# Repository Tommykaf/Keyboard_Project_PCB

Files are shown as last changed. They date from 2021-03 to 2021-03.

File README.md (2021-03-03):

# keyboard_project

A Keyboard pcb modeled by @tommykark03, @thunde7, @wifi and @staveyal

## Parts

- MCU: ATMEGA32U4
- USB: TYPE-C-31-M-12
- DIODE: 1N4148W SOD-123

RESISTORS:
- 22 OHM - 0603WAF220JT5E
- 10k OHM - 0603WAF1002T5E
- 5.1K OHM - 0603WAF5101T5E

CAPACITORS:
- 1uF - CL10A105KB8NNNC
- 10uF - CL10A106KP8NNNC 
- 0.1uF (100pF) - CL10C101JB8NNNC

Quartz:
- Yangxing Tech X252016MLD4SC

Tactile reset:
- PANASONIC EVPBB4A9B000

Ferrite Bead:
- GZ1608D601TF

## layout

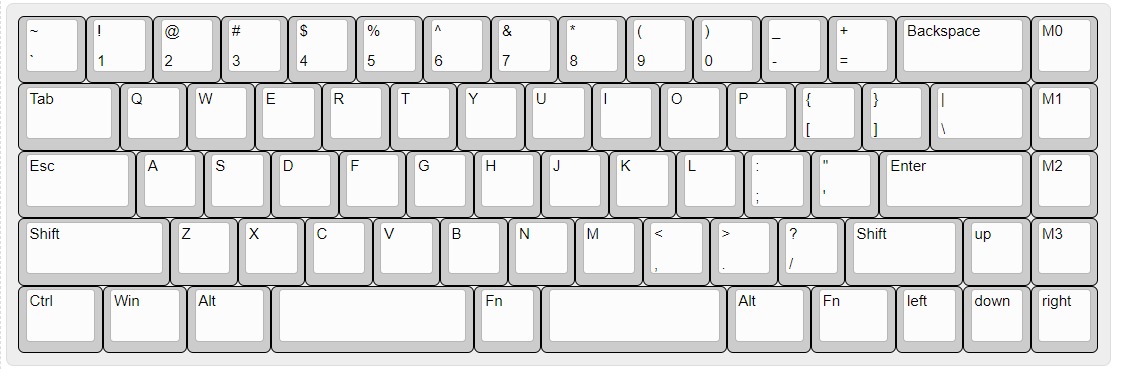
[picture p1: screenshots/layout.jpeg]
modified 65%


## MORE SCREENSHOTS
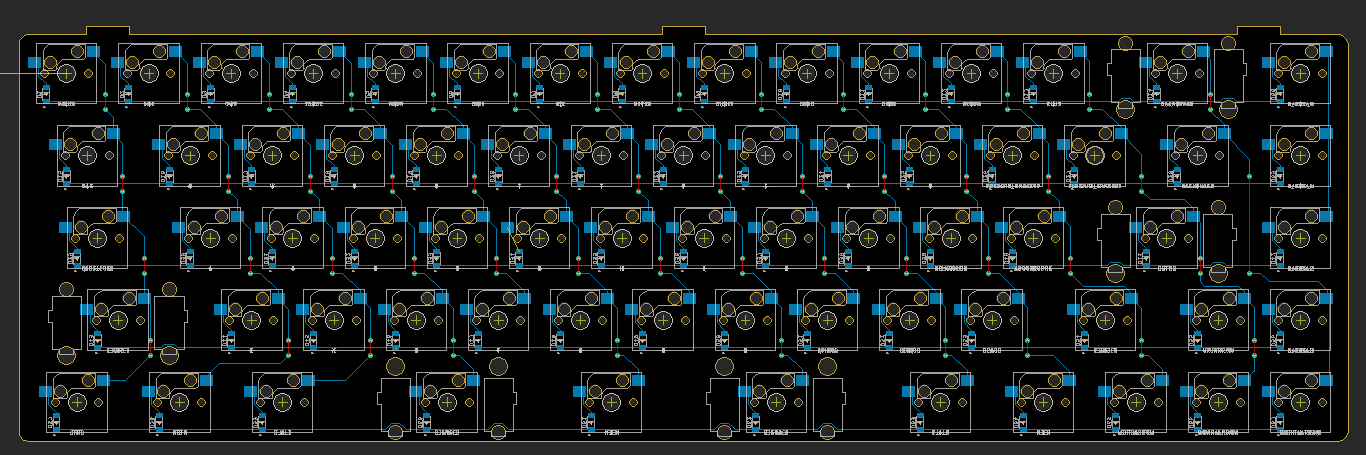
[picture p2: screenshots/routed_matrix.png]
routed matrix


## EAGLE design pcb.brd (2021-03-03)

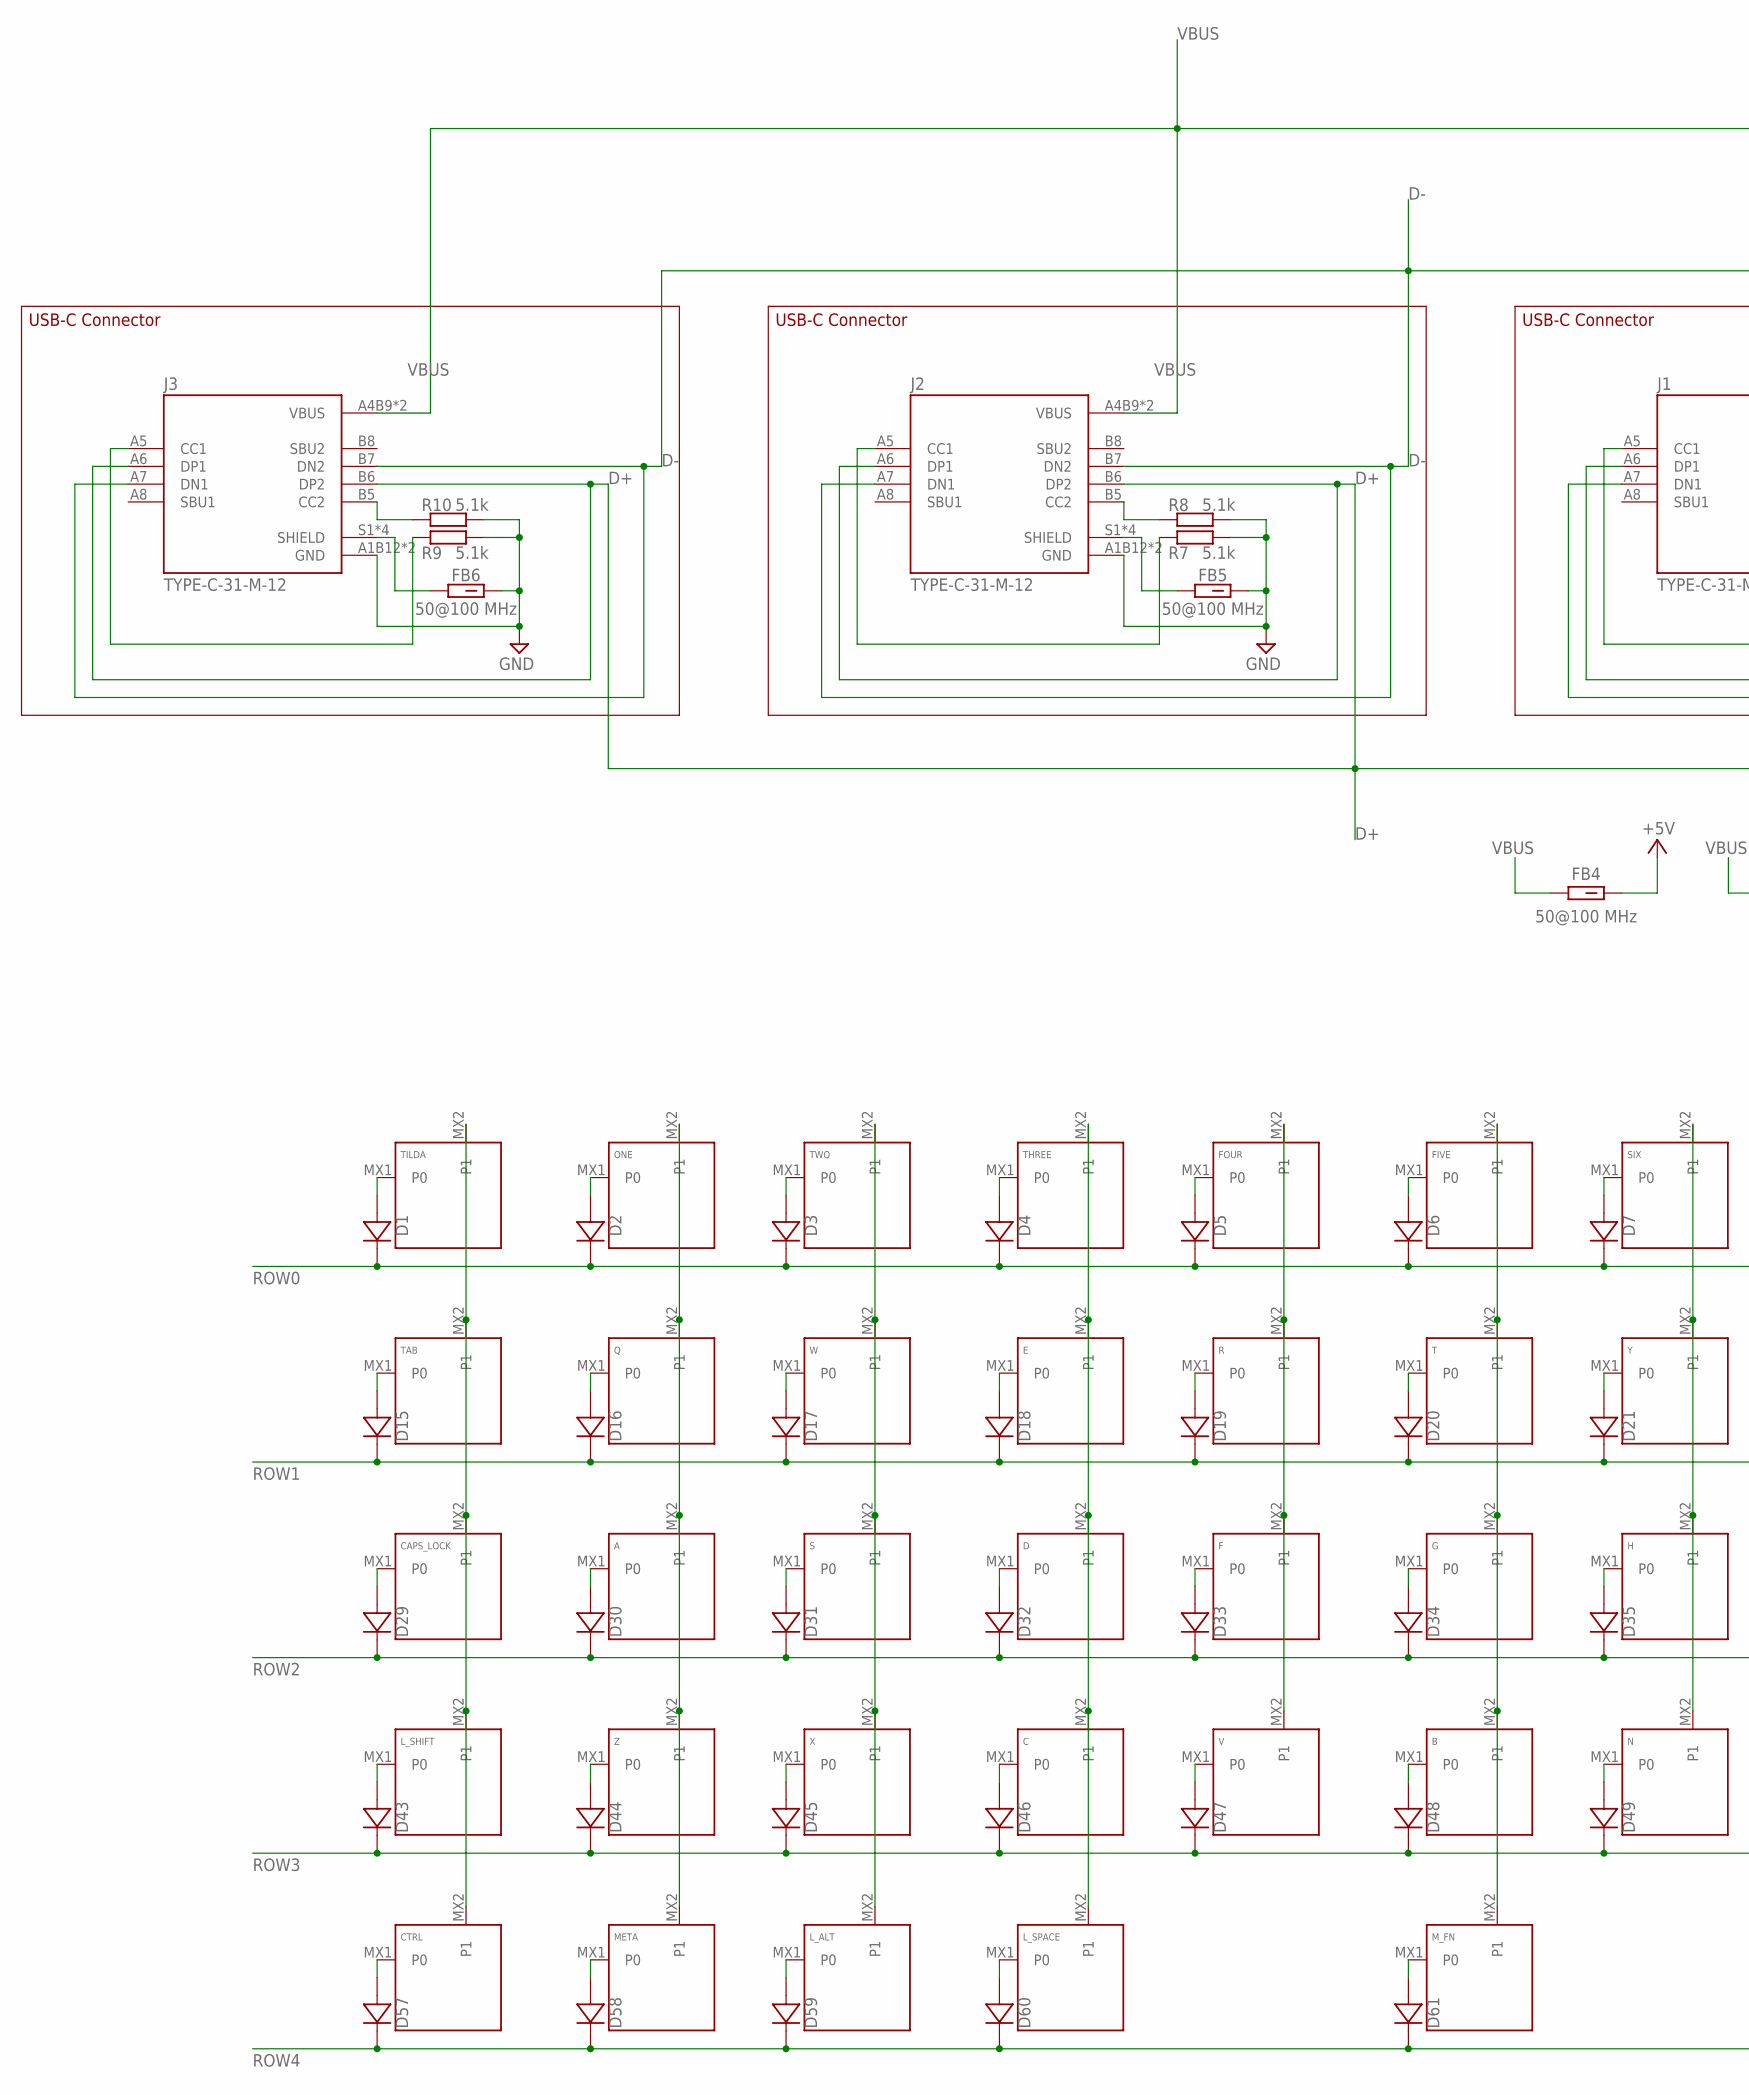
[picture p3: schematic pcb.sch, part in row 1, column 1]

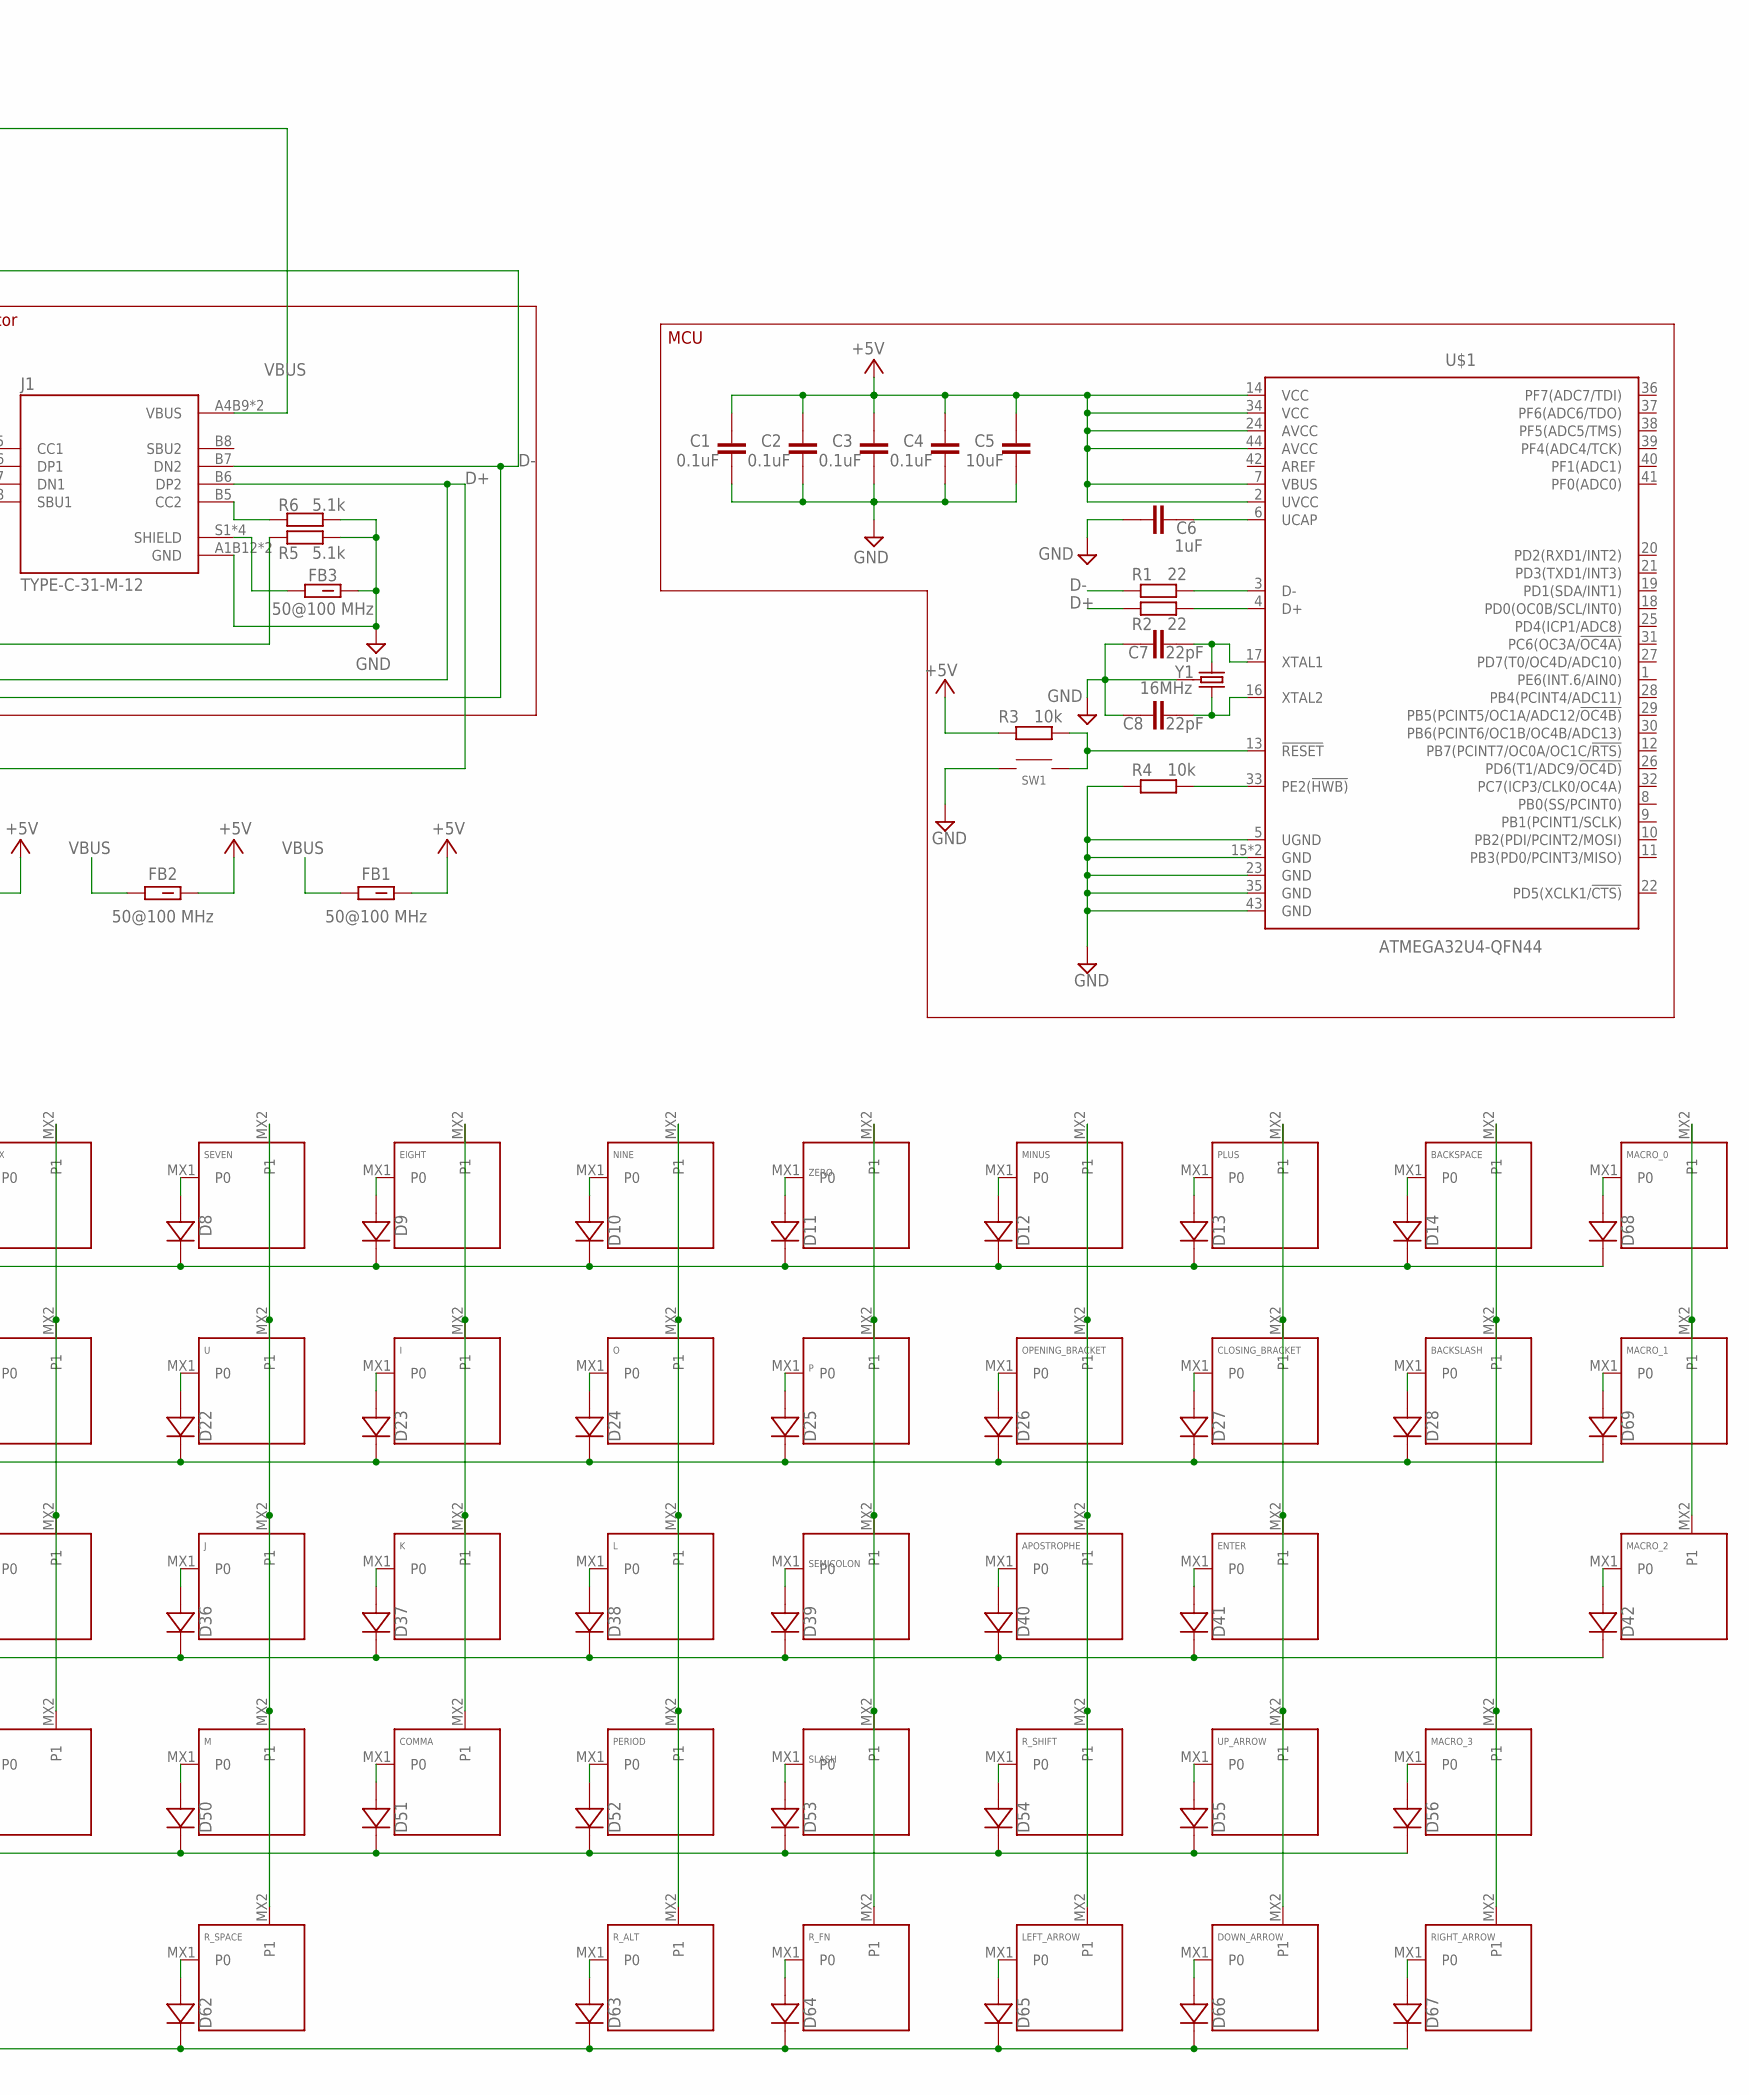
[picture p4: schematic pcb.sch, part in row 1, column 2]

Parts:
A: KEYSWITCH-PLAIN-MXHSPCB-1U; MXHSPCB-1U
APOSTROPHE: KEYSWITCH-PLAIN-MXHSPCB-1U; MXHSPCB-1U
B: KEYSWITCH-PLAIN-MXHSPCB-1U; MXHSPCB-1U
BACKSLASH: KEYSWITCH-PLAIN-MXHSPCB-1U; MXHSPCB-1U
BACKSPACE: KEYSWITCH-PLAIN-MXHSPCB-2U; MXHSPCB-2U
C: KEYSWITCH-PLAIN-MXHSPCB-1U; MXHSPCB-1U
C1, C2, C3, C4: 0.1uF; C0603
C5: 10uF; C0603
C6: 1uF; C0603
C7, C8: 22pF; C0603
CAPS_LOCK: KEYSWITCH-PLAIN-MXHSPCB-1U; MXHSPCB-1U
CLOSING_BRACKET: KEYSWITCH-PLAIN-MXHSPCB-1U; MXHSPCB-1U
COMMA: KEYSWITCH-PLAIN-MXHSPCB-1U; MXHSPCB-1U
CTRL: KEYSWITCH-PLAIN-MXHSPCB-1U; MXHSPCB-1U
D: KEYSWITCH-PLAIN-MXHSPCB-1U; MXHSPCB-1U
D1, D2, D3, D4, D5, D6, D7, D8, D9, D10, D11, D12, D13, D14, D15, D16, D17, D18, D19, D20, D21, D22, D23, D24, D25, D26, D27, D28, D29, D30, D31, D32, D33, D34, D35, D36, D37, D38, D39, D40, D41, D42, D43, D44, D45, D46, D47, D48, D49, D50, D51, D52, D53, D54, D55, D56, D57, D58, D59, D60, D61, D62, D63, D64, D65, D66, D67, D68, D69: DIODE-SOD-123; SOD-123
DOWN_ARROW: KEYSWITCH-PLAIN-MXHSPCB-1U; MXHSPCB-1U
E: KEYSWITCH-PLAIN-MXHSPCB-1U; MXHSPCB-1U
EIGHT: KEYSWITCH-PLAIN-MXHSPCB-1U; MXHSPCB-1U
ENTER: KEYSWITCH-PLAIN-MXHSPCB-2U; MXHSPCB-2U
F: KEYSWITCH-PLAIN-MXHSPCB-1U; MXHSPCB-1U
FB1, FB2, FB3, FB4, FB5, FB6: 50@100 MHz; BEADC1608X95N
FIVE: KEYSWITCH-PLAIN-MXHSPCB-1U; MXHSPCB-1U
FOUR: KEYSWITCH-PLAIN-MXHSPCB-1U; MXHSPCB-1U
G: KEYSWITCH-PLAIN-MXHSPCB-1U; MXHSPCB-1U
H: KEYSWITCH-PLAIN-MXHSPCB-1U; MXHSPCB-1U
I: KEYSWITCH-PLAIN-MXHSPCB-1U; MXHSPCB-1U
J: KEYSWITCH-PLAIN-MXHSPCB-1U; MXHSPCB-1U
J1, J2, J3: TYPE-C-31-M-12; HRO_TYPE-C-31-M-12
K: KEYSWITCH-PLAIN-MXHSPCB-1U; MXHSPCB-1U
L: KEYSWITCH-PLAIN-MXHSPCB-1U; MXHSPCB-1U
LEFT_ARROW: KEYSWITCH-PLAIN-MXHSPCB-1U; MXHSPCB-1U
L_ALT: KEYSWITCH-PLAIN-MXHSPCB-1U; MXHSPCB-1U
L_SHIFT: KEYSWITCH-PLAIN-MXHSPCB-2U; MXHSPCB-2U
L_SPACE: KEYSWITCH-PLAIN-MXHSPCB-2U-FLIPPED; MXHSPCB-2U-FLIPPED
M: KEYSWITCH-PLAIN-MXHSPCB-1U; MXHSPCB-1U
MACRO_0, MACRO_1, MACRO_2, MACRO_3: KEYSWITCH-PLAIN-MXHSPCB-1U; MXHSPCB-1U
META: KEYSWITCH-PLAIN-MXHSPCB-1U; MXHSPCB-1U
MINUS: KEYSWITCH-PLAIN-MXHSPCB-1U; MXHSPCB-1U
M_FN: KEYSWITCH-PLAIN-MXHSPCB-1U; MXHSPCB-1U
N: KEYSWITCH-PLAIN-MXHSPCB-1U; MXHSPCB-1U
NINE: KEYSWITCH-PLAIN-MXHSPCB-1U; MXHSPCB-1U
O: KEYSWITCH-PLAIN-MXHSPCB-1U; MXHSPCB-1U
ONE: KEYSWITCH-PLAIN-MXHSPCB-1U; MXHSPCB-1U
OPENING_BRACKET: KEYSWITCH-PLAIN-MXHSPCB-1U; MXHSPCB-1U
P: KEYSWITCH-PLAIN-MXHSPCB-1U; MXHSPCB-1U
PERIOD: KEYSWITCH-PLAIN-MXHSPCB-1U; MXHSPCB-1U
PLUS: KEYSWITCH-PLAIN-MXHSPCB-1U; MXHSPCB-1U
Q: KEYSWITCH-PLAIN-MXHSPCB-1U; MXHSPCB-1U
R: KEYSWITCH-PLAIN-MXHSPCB-1U; MXHSPCB-1U
R1, R2: 22; R0603
R3, R4: 10k; R0603
R5, R6, R7, R8, R9, R10: 5.1k; R0603
RIGHT_ARROW: KEYSWITCH-PLAIN-MXHSPCB-1U; MXHSPCB-1U
R_ALT: KEYSWITCH-PLAIN-MXHSPCB-1U; MXHSPCB-1U
R_FN: KEYSWITCH-PLAIN-MXHSPCB-1U; MXHSPCB-1U
R_SHIFT: KEYSWITCH-PLAIN-MXHSPCB-1U; MXHSPCB-1U
R_SPACE: KEYSWITCH-PLAIN-MXHSPCB-2U-FLIPPED; MXHSPCB-2U-FLIPPED
S: KEYSWITCH-PLAIN-MXHSPCB-1U; MXHSPCB-1U
SEMICOLON: KEYSWITCH-PLAIN-MXHSPCB-1U; MXHSPCB-1U
SEVEN: KEYSWITCH-PLAIN-MXHSPCB-1U; MXHSPCB-1U
SIX: KEYSWITCH-PLAIN-MXHSPCB-1U; MXHSPCB-1U
SLASH: KEYSWITCH-PLAIN-MXHSPCB-1U; MXHSPCB-1U
SW1: SWITCH-SMD-EVP-BB2A9B00
T: KEYSWITCH-PLAIN-MXHSPCB-1U; MXHSPCB-1U
TAB: KEYSWITCH-PLAIN-MXHSPCB-1U; MXHSPCB-1U
THREE: KEYSWITCH-PLAIN-MXHSPCB-1U; MXHSPCB-1U
TILDA: KEYSWITCH-PLAIN-MXHSPCB-1U; MXHSPCB-1U
TWO: KEYSWITCH-PLAIN-MXHSPCB-1U; MXHSPCB-1U
U: KEYSWITCH-PLAIN-MXHSPCB-1U; MXHSPCB-1U
U$1: ATMEGA32U4-QFN44; QFN-44
UP_ARROW: KEYSWITCH-PLAIN-MXHSPCB-1U; MXHSPCB-1U
V: KEYSWITCH-PLAIN-MXHSPCB-1U; MXHSPCB-1U
W: KEYSWITCH-PLAIN-MXHSPCB-1U; MXHSPCB-1U
X: KEYSWITCH-PLAIN-MXHSPCB-1U; MXHSPCB-1U
Y: KEYSWITCH-PLAIN-MXHSPCB-1U; MXHSPCB-1U
Y1: 16MHz; CRYSTAL-SMD-2X2.5MM
Z: KEYSWITCH-PLAIN-MXHSPCB-1U; MXHSPCB-1U
ZERO: KEYSWITCH-PLAIN-MXHSPCB-1U; MXHSPCB-1U

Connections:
+5V: FB1.2, FB2.2, FB4.2
D+: J1.A6 (DP1), J1.B6 (DP2), J2.A6 (DP1), J2.B6 (DP2), J3.A6 (DP1), J3.B6 (DP2), R2.1
D-: J1.A7 (DN1), J1.B7 (DN2), J2.A7 (DN1), J2.B7 (DN2), J3.A7 (DN1), J3.B7 (DN2), R1.1
GND: C1.1, C2.1, C3.1, C4.1, C5.1, C6.1, C7.1, C8.1, FB3.2, FB5.2, FB6.2, J1.A1B12 (GND), J1.B1A12 (GND), J2.A1B12 (GND), J2.B1A12 (GND), J3.A1B12 (GND), J3.B1A12 (GND), R4.1, R5.2, R6.2, R7.2, R8.2, R9.2, R10.2, SW1.A@1 (1), SW1.A@2 (1), U$1.5 (UGND), U$1.15 (GND), U$1.23 (GND), U$1.35 (GND), U$1.43 (GND), U$1.TAB (GND), Y1.P2 (GND), Y1.P4 (GND)
unnamed: D1.A, TILDA.MX1 (P0)
unnamed: D2.A, ONE.MX1 (P0)
unnamed: D3.A, TWO.MX1 (P0)
unnamed: D4.A, THREE.MX1 (P0)
unnamed: D5.A, FOUR.MX1 (P0)
unnamed: D6.A, FIVE.MX1 (P0)
unnamed: D7.A, SIX.MX1 (P0)
unnamed: D8.A, SEVEN.MX1 (P0)
unnamed: D9.A, EIGHT.MX1 (P0)
unnamed: D10.A, NINE.MX1 (P0)
unnamed: D11.A, ZERO.MX1 (P0)
unnamed: D12.A, MINUS.MX1 (P0)
unnamed: D13.A, PLUS.MX1 (P0)
unnamed: BACKSPACE.MX1 (P0), D14.A
unnamed: D15.A, TAB.MX1 (P0)
unnamed: D16.A, Q.MX1 (P0)
unnamed: D17.A, W.MX1 (P0)
unnamed: D18.A, E.MX1 (P0)
unnamed: D19.A, R.MX1 (P0)
unnamed: D20.A, T.MX1 (P0)
unnamed: D21.A, Y.MX1 (P0)
unnamed: D22.A, U.MX1 (P0)
unnamed: D23.A, I.MX1 (P0)
unnamed: D24.A, O.MX1 (P0)
unnamed: D25.A, P.MX1 (P0)
unnamed: D26.A, OPENING_BRACKET.MX1 (P0)
unnamed: CLOSING_BRACKET.MX1 (P0), D27.A
unnamed: BACKSLASH.MX1 (P0), D28.A
unnamed: CAPS_LOCK.MX1 (P0), D29.A
unnamed: A.MX1 (P0), D30.A
unnamed: D31.A, S.MX1 (P0)
unnamed: D.MX1 (P0), D32.A
unnamed: D33.A, F.MX1 (P0)
unnamed: D34.A, G.MX1 (P0)
unnamed: D35.A, H.MX1 (P0)
unnamed: D36.A, J.MX1 (P0)
unnamed: D37.A, K.MX1 (P0)
unnamed: D38.A, L.MX1 (P0)
unnamed: D39.A, SEMICOLON.MX1 (P0)
unnamed: APOSTROPHE.MX1 (P0), D40.A
unnamed: D41.A, ENTER.MX1 (P0)
unnamed: D42.A, MACRO_2.MX1 (P0)
unnamed: D43.A, L_SHIFT.MX1 (P0)
unnamed: D44.A, Z.MX1 (P0)
unnamed: D45.A, X.MX1 (P0)
unnamed: C.MX1 (P0), D46.A
unnamed: D47.A, V.MX1 (P0)
unnamed: B.MX1 (P0), D48.A
unnamed: D49.A, N.MX1 (P0)
unnamed: D50.A, M.MX1 (P0)
unnamed: COMMA.MX1 (P0), D51.A
unnamed: D52.A, PERIOD.MX1 (P0)
unnamed: D53.A, SLASH.MX1 (P0)
unnamed: D54.A, R_SHIFT.MX1 (P0)
unnamed: D55.A, UP_ARROW.MX1 (P0)
unnamed: D56.A, MACRO_3.MX1 (P0)
unnamed: CTRL.MX1 (P0), D57.A
unnamed: D58.A, META.MX1 (P0)
unnamed: D59.A, L_ALT.MX1 (P0)
unnamed: D60.A, L_SPACE.MX1 (P0)
unnamed: D62.A, R_SPACE.MX1 (P0)
unnamed: D63.A, R_ALT.MX1 (P0)
unnamed: D65.A, LEFT_ARROW.MX1 (P0)
unnamed: D67.A, RIGHT_ARROW.MX1 (P0)
unnamed: D69.A, MACRO_1.MX1 (P0)
unnamed: D68.A, MACRO_0.MX1 (P0)
unnamed: D61.A, M_FN.MX1 (P0)
unnamed: D66.A, DOWN_ARROW.MX1 (P0)
unnamed: D64.A, R_FN.MX1 (P0)
unnamed: CAPS_LOCK.MX2 (P1), CTRL.MX2 (P1), L_SHIFT.MX2 (P1), TAB.MX2 (P1), TILDA.MX2 (P1)
unnamed: A.MX2 (P1), META.MX2 (P1), ONE.MX2 (P1), Q.MX2 (P1), Z.MX2 (P1)
unnamed: L_ALT.MX2 (P1), S.MX2 (P1), TWO.MX2 (P1), W.MX2 (P1), X.MX2 (P1)
unnamed: C.MX2 (P1), D.MX2 (P1), E.MX2 (P1), L_SPACE.MX2 (P1), THREE.MX2 (P1)
unnamed: F.MX2 (P1), FOUR.MX2 (P1), R.MX2 (P1), V.MX2 (P1)
unnamed: B.MX2 (P1), FIVE.MX2 (P1), G.MX2 (P1), M_FN.MX2 (P1), T.MX2 (P1)
unnamed: H.MX2 (P1), N.MX2 (P1), SIX.MX2 (P1), Y.MX2 (P1)
unnamed: J.MX2 (P1), M.MX2 (P1), R_SPACE.MX2 (P1), SEVEN.MX2 (P1), U.MX2 (P1)
unnamed: COMMA.MX2 (P1), EIGHT.MX2 (P1), I.MX2 (P1), K.MX2 (P1)
unnamed: L.MX2 (P1), NINE.MX2 (P1), O.MX2 (P1), PERIOD.MX2 (P1), R_ALT.MX2 (P1)
unnamed: APOSTROPHE.MX2 (P1), LEFT_ARROW.MX2 (P1), MINUS.MX2 (P1), OPENING_BRACKET.MX2 (P1), R_SHIFT.MX2 (P1)
unnamed: P.MX2 (P1), R_FN.MX2 (P1), SEMICOLON.MX2 (P1), SLASH.MX2 (P1), ZERO.MX2 (P1)
unnamed: CLOSING_BRACKET.MX2 (P1), DOWN_ARROW.MX2 (P1), ENTER.MX2 (P1), PLUS.MX2 (P1), UP_ARROW.MX2 (P1)
unnamed: BACKSLASH.MX2 (P1), BACKSPACE.MX2 (P1), MACRO_3.MX2 (P1), RIGHT_ARROW.MX2 (P1)
unnamed: MACRO_0.MX2 (P1), MACRO_1.MX2 (P1), MACRO_2.MX2 (P1)
unnamed: R4.2, U$1.33 (PE2(!HWB))
unnamed: R3.2, SW1.B@3 (2), SW1.B@4 (2), U$1.13 (!RESET)
unnamed: C7.2, U$1.17 (XTAL1), Y1.P1 (1)
unnamed: C8.2, U$1.16 (XTAL2), Y1.P3 (2)
unnamed: R2.2, U$1.4 (D+)
unnamed: R1.2, U$1.3 (D-)
unnamed: C6.2, U$1.6 (UCAP)
unnamed: J2.A5 (CC1), R7.1
unnamed: J1.A5 (CC1), R5.1
unnamed: J1.B5 (CC2), R6.1
unnamed: J2.B5 (CC2), R8.1
unnamed: FB5.1, J2.S1 (SHIELD), J2.S2 (SHIELD), J2.S3 (SHIELD), J2.S4 (SHIELD)
unnamed: J3.A5 (CC1), R9.1
unnamed: FB3.1, J1.S1 (SHIELD), J1.S2 (SHIELD), J1.S3 (SHIELD), J1.S4 (SHIELD)
unnamed: J3.B5 (CC2), R10.1
unnamed: FB6.1, J3.S1 (SHIELD), J3.S2 (SHIELD), J3.S3 (SHIELD), J3.S4 (SHIELD)
ROW0: D1.C, D2.C, D3.C, D4.C, D5.C, D6.C, D7.C, D8.C, D9.C, D10.C, D11.C, D12.C, D13.C, D14.C, D68.C
ROW1: D15.C, D16.C, D17.C, D18.C, D19.C, D20.C, D21.C, D22.C, D23.C, D24.C, D25.C, D26.C, D27.C, D28.C, D69.C
ROW2: D29.C, D30.C, D31.C, D32.C, D33.C, D34.C, D35.C, D36.C, D37.C, D38.C, D39.C, D40.C, D41.C, D42.C
ROW3: D43.C, D44.C, D45.C, D46.C, D47.C, D48.C, D49.C, D50.C, D51.C, D52.C, D53.C, D54.C, D55.C, D56.C
ROW4: D57.C, D58.C, D59.C, D60.C, D61.C, D62.C, D63.C, D64.C, D65.C, D66.C, D67.C
VBUS: FB1.1, FB2.1, FB4.1, J1.A4B9 (VBUS), J1.B4A9 (VBUS), J2.A4B9 (VBUS), J2.B4A9 (VBUS), J3.A4B9 (VBUS), J3.B4A9 (VBUS)
VCC: C1.2, C2.2, C3.2, C4.2, C5.2, R3.1, U$1.2 (UVCC), U$1.7 (VBUS), U$1.14 (VCC), U$1.24 (AVCC), U$1.34 (VCC), U$1.44 (AVCC)

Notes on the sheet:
USB-C Connector
MCU

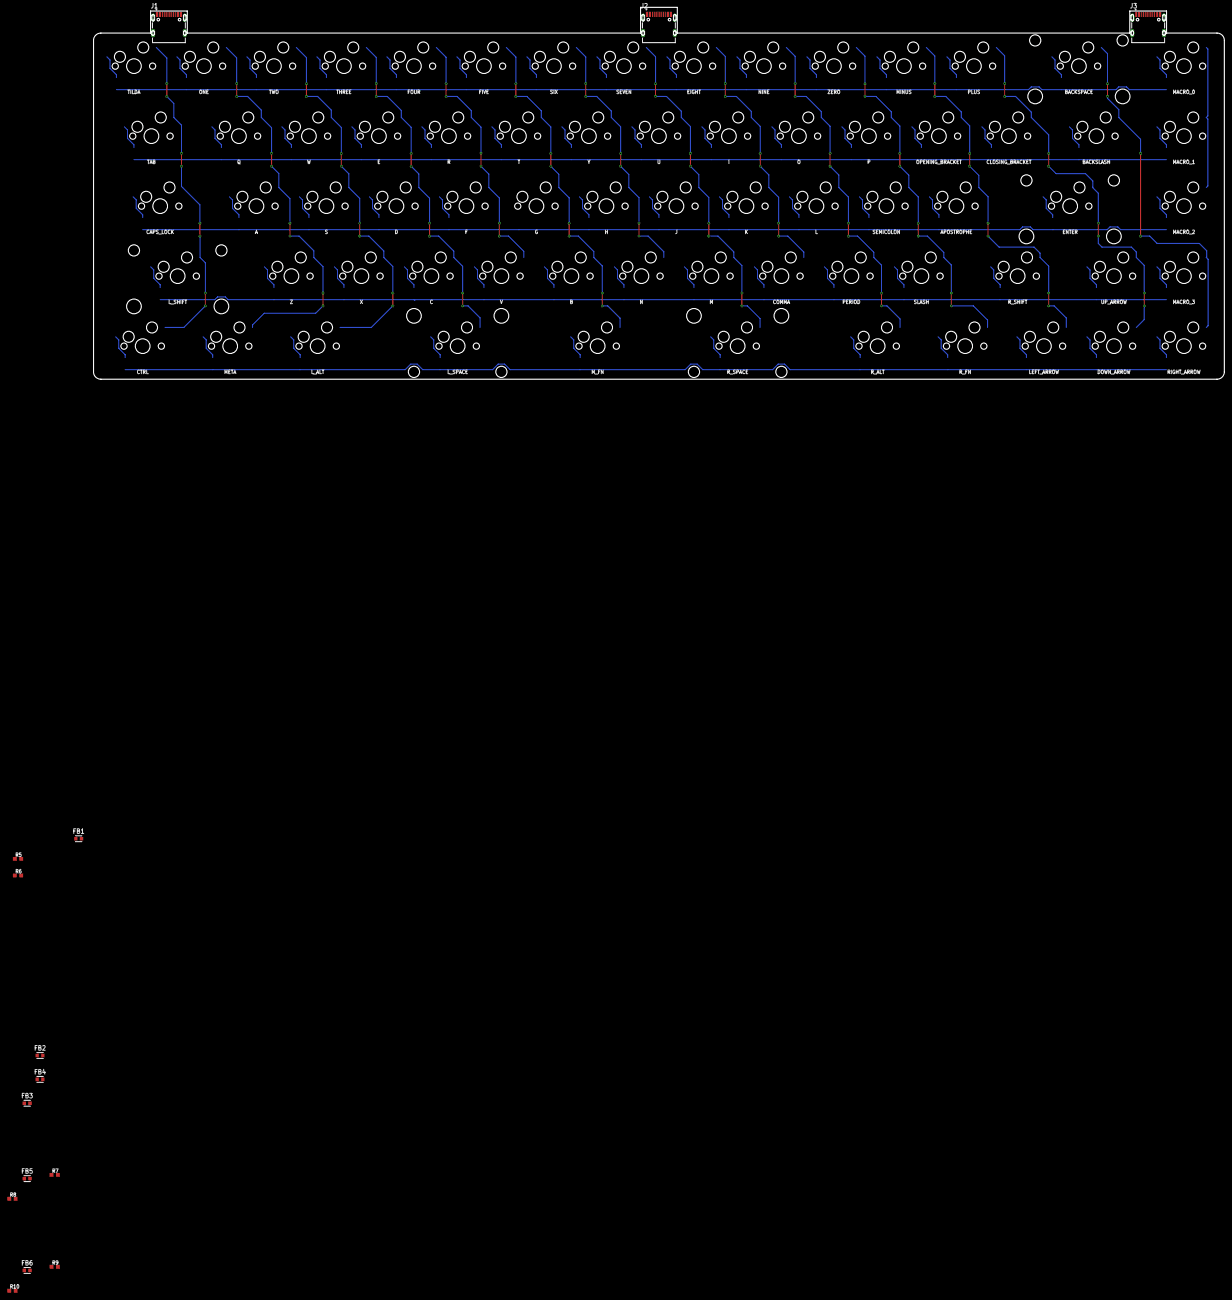
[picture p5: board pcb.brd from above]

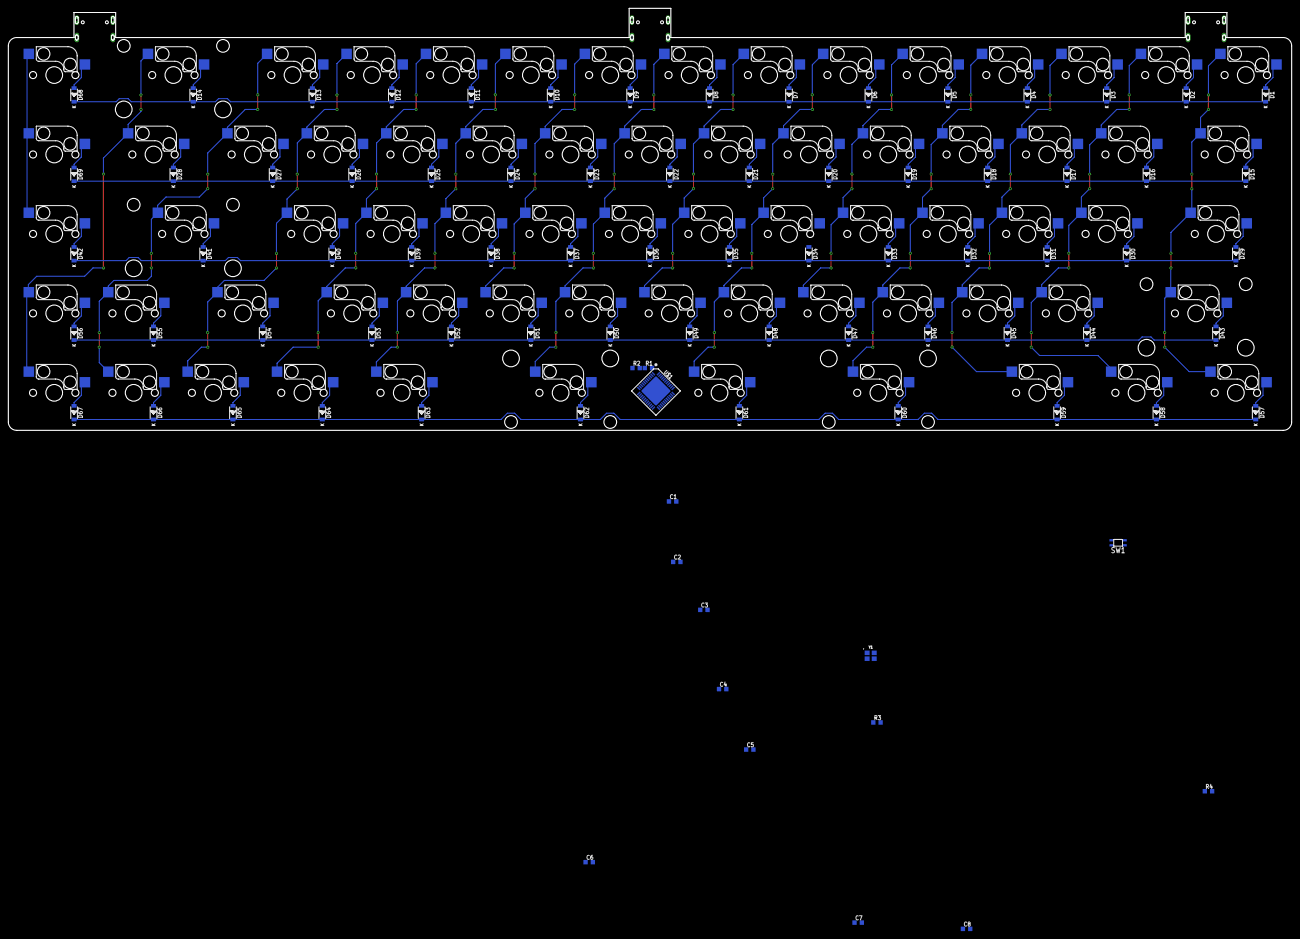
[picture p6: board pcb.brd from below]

Board: 2 copper layers, 307.8 x 101.2 mm, 168 parts (153 on the bottom side), 111 nets.

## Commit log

2021-02-19 inital commit - added switches, diodes, etc...
    [pcb.brd, pcb.sch]
2021-02-19 removed stray net
    [pcb.sch]
2021-02-20 updated matrix and streched pcb
    [pcb.brd, pcb.sch]
2021-03-02 added MCU scheme + readme
    [pcb.brd, pcb.sch]
2021-03-03 added USB-C + ferrite beads
    [pcb.brd, pcb.sch]

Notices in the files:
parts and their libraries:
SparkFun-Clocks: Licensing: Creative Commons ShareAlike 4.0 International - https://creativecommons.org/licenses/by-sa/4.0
